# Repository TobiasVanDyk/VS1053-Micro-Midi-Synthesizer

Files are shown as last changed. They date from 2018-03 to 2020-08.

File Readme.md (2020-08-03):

# VS1053 Micro Midi Synthesizer

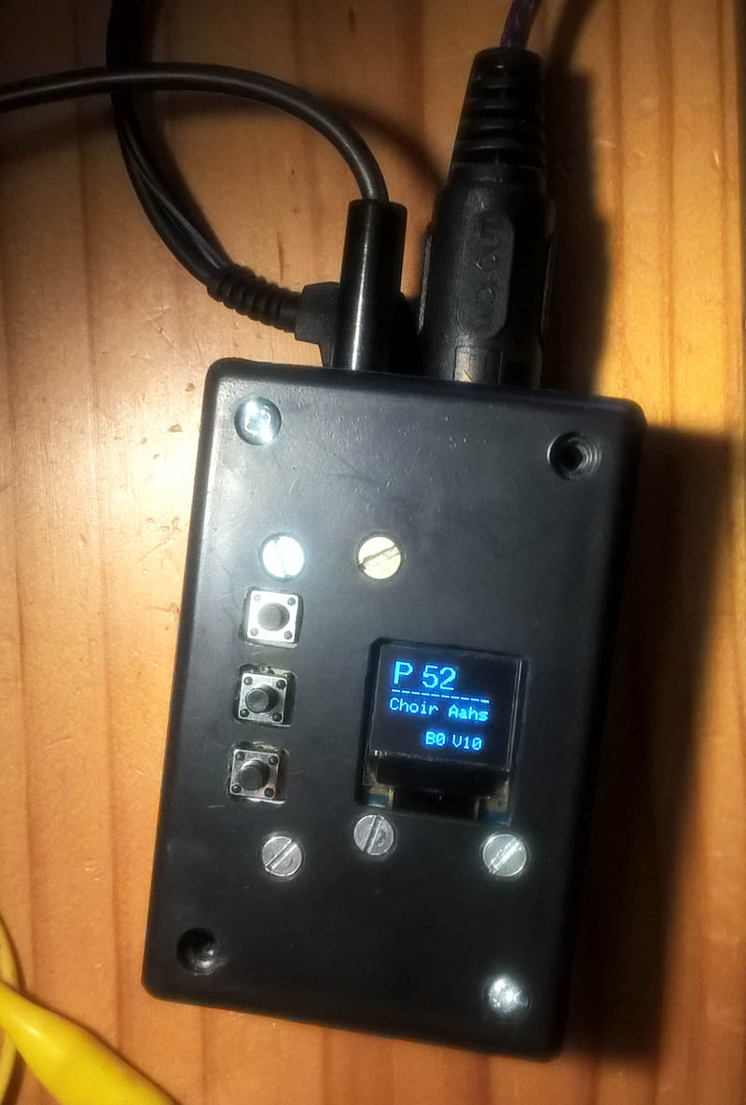
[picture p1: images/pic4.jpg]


### Introduction: 

This is also available as an [**instructable**](https://www.instructables.com/id/Micro-Midi-Synthesizer/), and demonstrates the use of the VLSI VS1053b Audio and Midi DSP chip in its real-time Midi mode. In this mode it acts as a 64 voice polyphonic GM (General Midi) Midi synthesizer. 

An ATMega328 MCU controls an OLED display, three buttons (Function Select and Up or Down, and passes the Midi data stream through to the audio DSP. The music board chosen was the Adafruit VS1053 codec breakout board, but a Sparkfun music breakout board was also successfully tested. The Adafruit VS1053b libraries were used instead of the much larger SFEMP3 Library (recommended by Sparkfun even though they also have their own set of libraries), because I found the Adafruit code easier to understand.

Most of the code used to control the audio/midi DSP was developed using an Arduino Uno connected to the audio/midi breakout board through a breadboard. After the functions were found to work satisfactory the Uno was used as a programmer for a standalone ATmega 328 which was then put on a small 30x20 size Veroboard together with the 6N139 opto-isolator IC required on the Midi input socket (a 5 pin DIN). Also connected was a small (64x48) OLED shield, three buttons, a Midi activity LED, and a +5 volt barrel connector for power and the audio stereo output connector added. The power requirements are very modest - about 20 mA at 5 volt.

### Parts List

* ATmega328 Micro 28 pin DIP + 28 pin DIP socket 
* 6N138 or 6N139 optoisolator + 4 pin DIP socket 
* Wemos 64x48 I2C OLED Display or similar 
* Adafruit VS1053b Codec breakout board 
* 3 miniature pushbuttons 
* 5 pin DIN Midi socket PCB mount preferred 
* Small LED any colour
* Barrel type power socket for the 5v supply 
* Stereo audio socket to connect to an amplifier or headphones 
* Resistors: 7 x 10k, 2 x 470 ohm, 2 x 220 ohm 
* Capacitors: 0.1uF 50v plastic, 10uf 25v electrolytic, 2 x 27 pF ceramic 
* Small pieces of Veroboard (30 strips by 20 columns, and 4 strips by 16 columns), ABS plastic enclosure about 85x55x25mm, wiring and a few screws nuts and washers.

### Construction

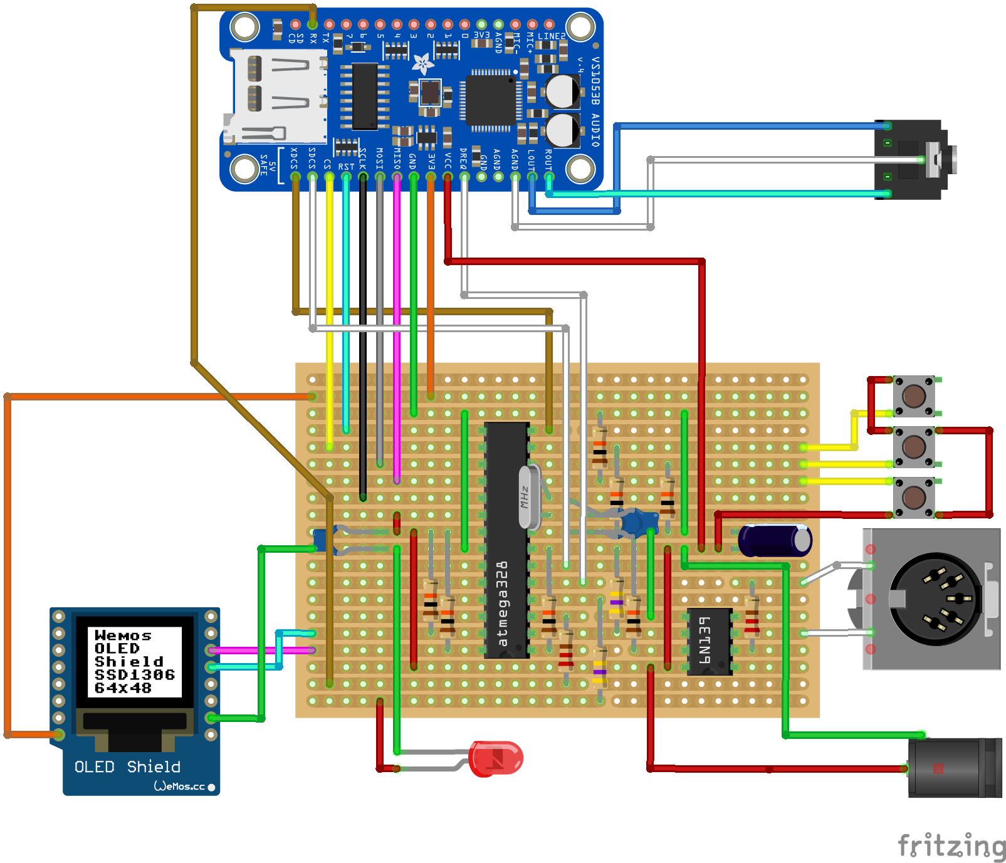
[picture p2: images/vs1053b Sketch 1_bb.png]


The lid of the enclosure houses the OLED Display, the three buttons that are mounted on another small piece of Veroboard, and the barrel power connector. The main Vero circuit board has two holes to fix the Music breakout board above the ATmega328. For connection details please refer to the Fritzing strip board diagram.
The programmed ATmega328 (please refer to the next section for the code) is then inserted into its socket followed by the 6N139 and everything is connected up.
The LED is used as a Midi activity indicator and was mounted on the front side of the enclosure. It is connected to the D2 output of the ATmega328 via a 470 ohm resistor.
The OLED Display use the 3.3 volt output from the Adafruit board for power - it requires less than 20 mA.
Try swapping the two Midi Din connections if you do not hear any audio when you first use the synth.

<p align="center">
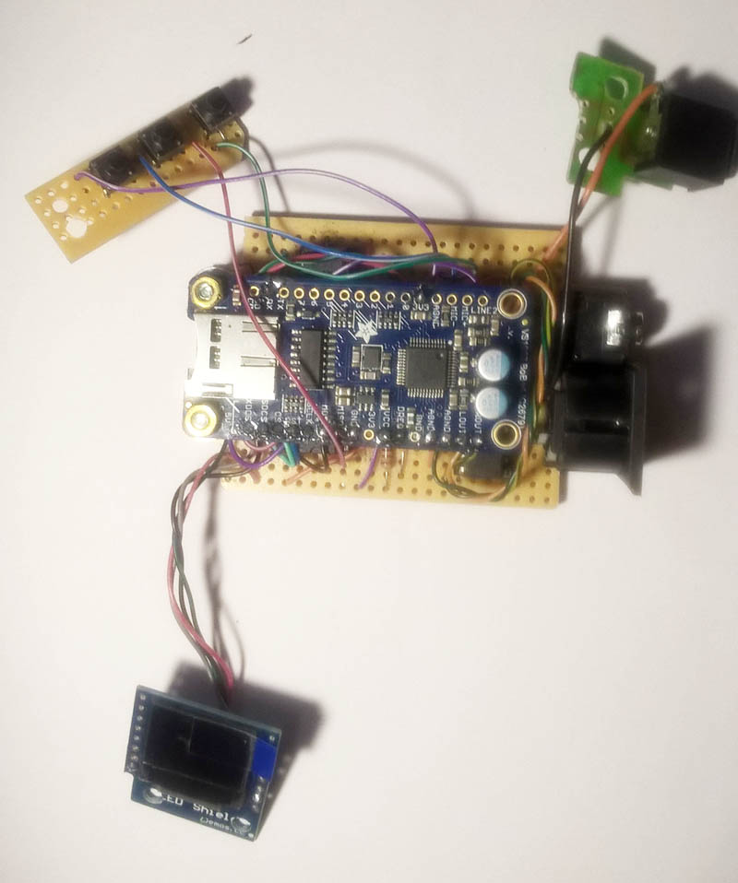
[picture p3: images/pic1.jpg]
  
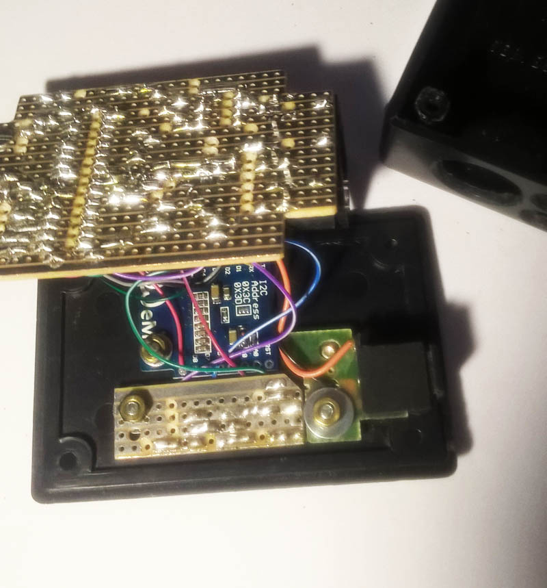
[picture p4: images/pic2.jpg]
  
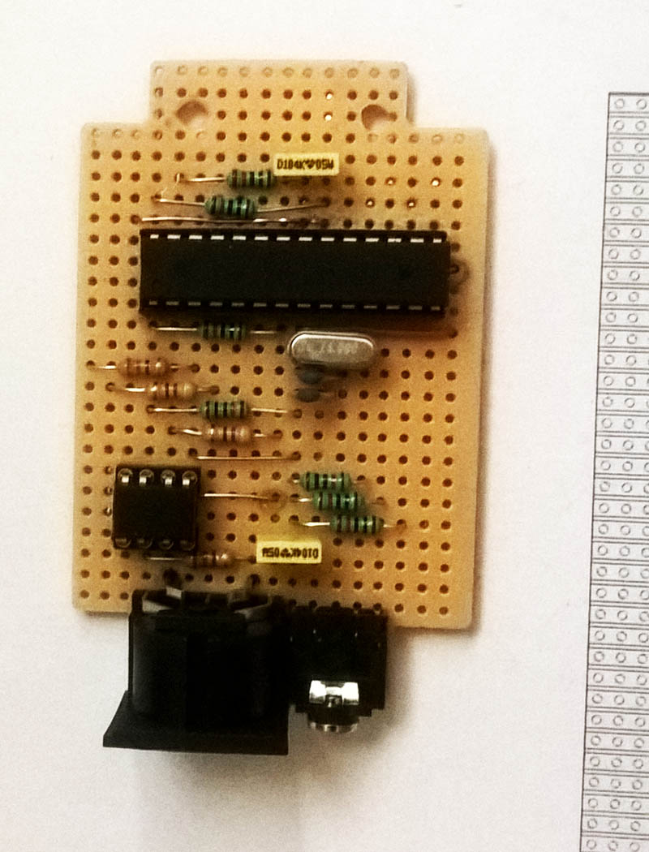
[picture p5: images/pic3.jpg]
  
</p>

### Software

Details of the sketch that should be uploaded to the ATmega328 is given in MidA.ino. There are seven functions available:
Option P: Change Program - change the GM Midi Instrument from 1 to 128 (I used 0 to 127) such as a Piano or Synth sound. Option B: Change the Instrument bank between Melodic (Bank 0) and Percussion (Bank 1). Option V: Adjust the volume from 1 to 10. Option C: Change the Midi channel that the Synth will respond to. The choices are Channel 0, channel 1, channel 9 (percussion), channel 0 and 9, and channel 1 and 9. Option R: Switch the Reverb effect on or off. Option S: Save the current parameters to Eeprom memory (Up) or Read (Down) it back from the Eeprom memory. This is because settings are otherwise not saved when powering down. Option X: Send an all notes off message (Midi Reset).

An eighth option is not yet implemented - this will bypass the ATmega as a Midi filter and connect the output of the optoisolator directly to the Rx pin of the DSP board.

Note that the VS1053b boots in a real-time Midi mode by loading a 1039 byte compressed patch during booting - this also increases the size of the Midi buffer and filters system exclusive Midi data bytes. Details of this patch can be found on the VLSI website.

A slightly modified version of the Adafruit Graphics library had been used to cater for the 64x48 pixel resolution of the OLED Display - please refer to the links given at the end for Mr Mcauser. A list of the required libraries is given in the sketch code.

Importantly when the sketch is executed for the first time on the ATmega328 whether it is on an Uno or standalone, the code will load parameter presets from the ATmega328 Eeprom that may not be valid. In that case you can either write all zeroes to the Eeprom using the X option with the down button, or comment out the line in the void setup function that loads values from the Eeprom when it is first started, adjust your instruments etc. to your liking, and then save your presets with the S option Up button.

Credit is given to all the persons and entities mentioned for their code and libraries..

### Links

* VLSI: http://www.vlsi.fi/en/home.html
* Adafruit: https://www.adafruit.com/product/1381
* Github VS1053b: https://github.com/adafruit/Adafruit_VS1053_Library
* Github Graphics: https://github.com/mcauser/Adafruit_SSD1306/tree/esp8266-64x48
* Oled: https://wiki.wemos.cc/products:d1_mini_shields:oled_shield
* Sparkfun: https://www.sparkfun.com/products/12660

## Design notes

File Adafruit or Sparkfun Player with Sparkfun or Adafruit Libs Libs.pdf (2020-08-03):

Use Adafruit Player with Sparkfun SFEMP Libraries:

Connect Adafruit Player to Arduino Uno pins using the Sparkfun layout (green = same connection):

Connect Sparkfun Player to Arduino Uno pins using the Adafruit layout (green = same connection):

Adafruit → | Uno – SparkfunLibs | Uno – Afafruit Libs | Sparkfun
Shield | | | Shield
VCC | 5v | 5v | 5v
GND | GND | GND | GND
SCLK | Arduino #13 | Arduino #13 | 13
MISO | Arduino #12 | Arduino #12 | 12
MOSI | Arduino #11 | Arduino #11 | 10
CS | Arduino #6 | Arduino #10 | 6 MP3-CS
RST | Arduino #8 | Arduino #9 | 8 MP3-RST
XDCS | Arduino #7 | Arduino #8 | 7 MP3-DCS
SDCS | Arduino #9 | Arduino #4 | 9 SC-CS
DREQ | Arduino #2 | Arduino #3 | 2 MP3-DREQ
RX-Midi | Arduino #3
| Arduino Tx #1 | | 3 MIDI-IN RX

Adafruit Shield with SFEMP3 Libs: GPIO1 and GPIO0 can be left unconnected or connected to GND.
Can now use the SFEMP3Shield libraries on the Adafruit.
To play Flac must put patchesf.053 in root of SD Card and change patches.053 to patchesf.053 in SFEMP3Shield.cpp. Then use FilePlayer.ino with indexes ie.e 0005 etc to select the .fla file (not .flac).
MP3Shield_Library_Demo.ino only able to play .mp3 files else must change the code.

Sparkfun Shield with SFEMP3 Libs: Pins 5 and 4 leave unconnected

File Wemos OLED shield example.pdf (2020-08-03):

Wemos OLED shield example

In this example we look at another terrific little low cost shield for the Wemos mini, this time its the OLED shield. Lets look at the shield and some specs

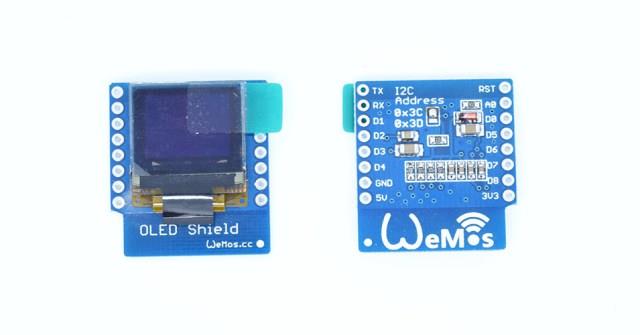
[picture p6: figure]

- Screen Size: 64×48 pixels (0.66” Across)
- Operating Voltage: 3.3V
- Driver IC: SSD1306
- Interface: IIC(I2C)
- IIC Address: 0x3C or 0x3D

The shield uses the I2C pins, so you can still connect another I2C device (if it uses a different address) and the other pins are available

D1 mini | Shield
D1 | SCL
D2 | SDA

Code

You will need to add the https://github.com/mcauser/Adafruit_SSD1306 library

The following code example is a simple hello world type example

Source code (http://www.esp8266learning.com/wemos-oled-shield-example.php#codesyntax_3)

#include <SPI.h>

#include <Wire.h>

#include <Adafruit_GFX.h>

#include <Adafruit_SSD1306.h>

// SCL GPIO5
// SDA GPIO4
#define OLED_RESET 0 // GPIO0 Adafruit_SSD1306 display(OLED_RESET);

#define NUMFLAKES 10

#define XPOS 0

#define YPOS 1

#define DELTAY 2

#define LOGO16_GLCD_HEIGHT 16

#define LOGO16_GLCD_WIDTH | 16

void setup() | {
Serial.begin(9600);

// by default, we'll generate the high voltage from the 3.3v line internally! (neat!) display.begin(SSD1306_SWITCHCAPVCC, 0x3C); // initialize with the I2C addr 0x3C (for the 64x48)
// init done

display.display();
delay(2000);

// Clear the buffer.
display.clearDisplay();

// text display tests
display.setTextSize(1);
display.setTextColor(WHITE); display.setCursor(0,0);
display.println("Hello, world!"); display.display();
delay(2000);
display.clearDisplay();

}

void loop() {

}

Links
OLED Shield for WeMos D1 mini 0.66″ inch 64X48 IIC I2C Compatible (http://s.click.aliexpress.com/e/3RFYr7YRV)
4 comments to Wemos OLED shield example

Mike Morrow
28th August 2017 at 7:46 am · Reply

Here’s what I had to do to see anything on the screen. (0,0) is too high and too far left

// text display tests
display.setTextSize(1);
display.setTextColor(WHITE);
display.setCursor(32,20);
display.println(“Hello, world!”); display.display();

HYKGOML
1st October 2017 at 2:32 am · Reply

// text display tests
display.setTextSize(1);
display.setTextColor(WHITE); display.setCursor(31,8);
display.println(“123456789AB”); display.setCursor(31,16);
display.println(“123456789AB”); display.setCursor(31,24);
display.println(“123456789AB”); display.display();
delay(2000);

display.clearDisplay();

Miguel Angel Casanova
7th October 2017 at 9:09 pm · Reply

Thanks Mike Morrow, you are right! ..

Greg Woods
12th October 2017 at 12:49 am · Reply

@Mike Morrow. It’s because the Adafruit library isn’t designed for 64*48 displays. A forked version will likely work. It’s just finding one that is the problem. There are 326 forks… of varying quality!

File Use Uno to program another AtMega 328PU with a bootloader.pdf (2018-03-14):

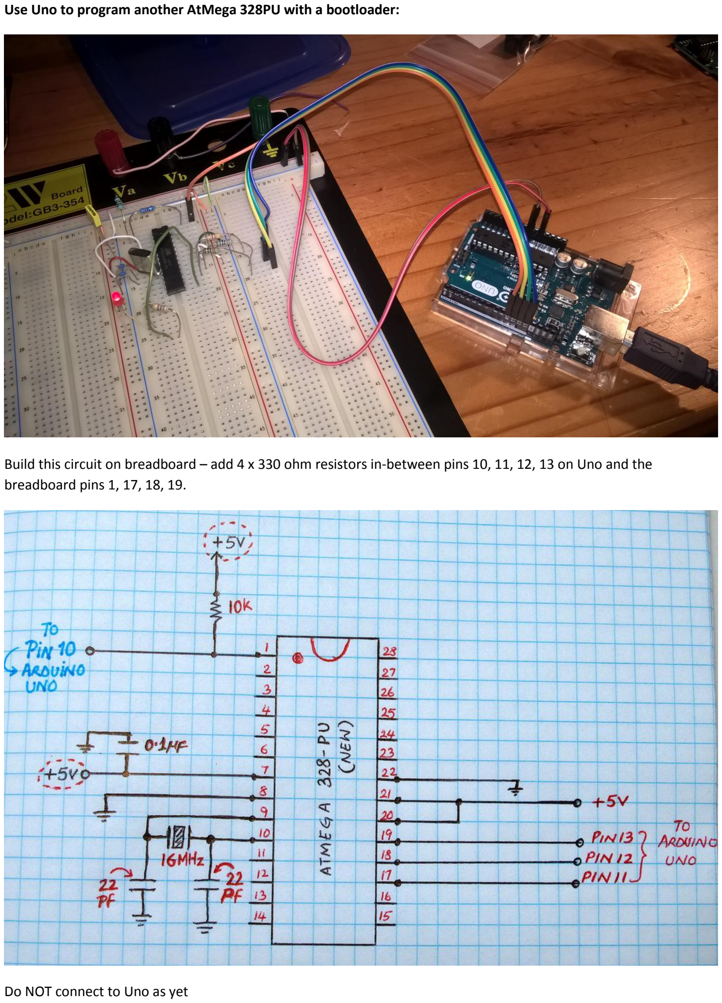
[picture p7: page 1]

Use Uno to program another AtMega 328PU with a bootloader:

Build this circuit on breadboard – add 4 x 330 ohm resistors in-between pins 10, 11, 12, 13 on Uno and the breadboard pins 1, 17, 18, 19.

Do NOT connect to Uno as yet

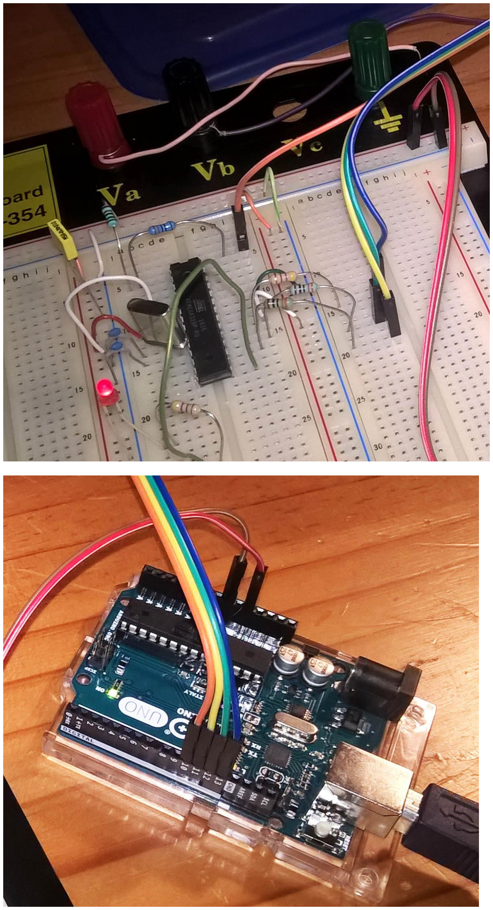
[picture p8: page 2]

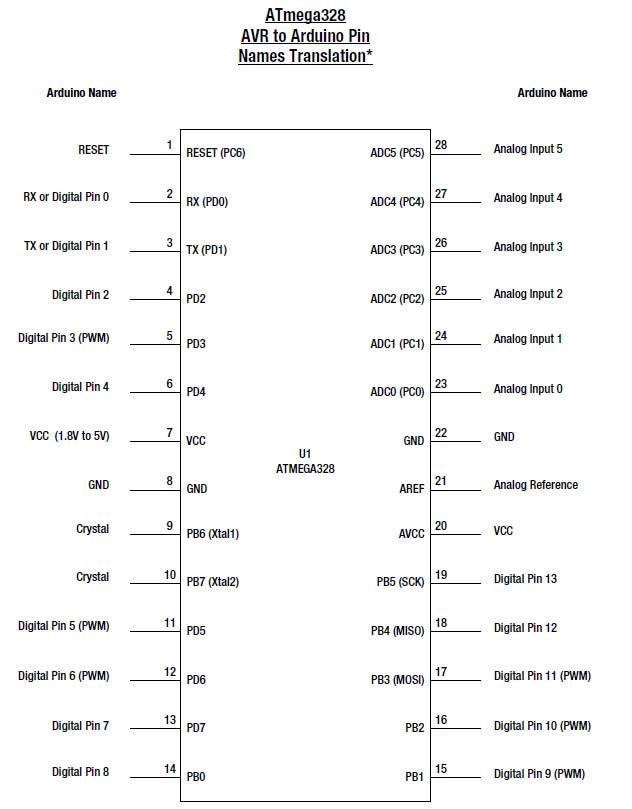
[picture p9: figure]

Connect Uno with an usb cable and start Arduino ide

Check that correct com port is chosen (if another Uno is plugged in it will have a different com number)

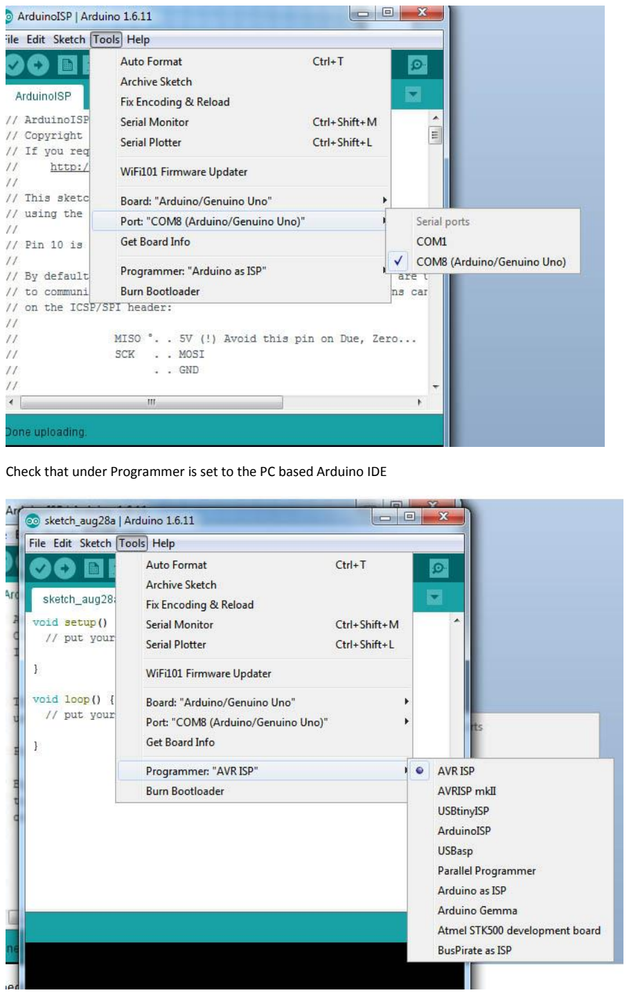
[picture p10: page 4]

Check that under Programmer is set to the PC based Arduino IDE

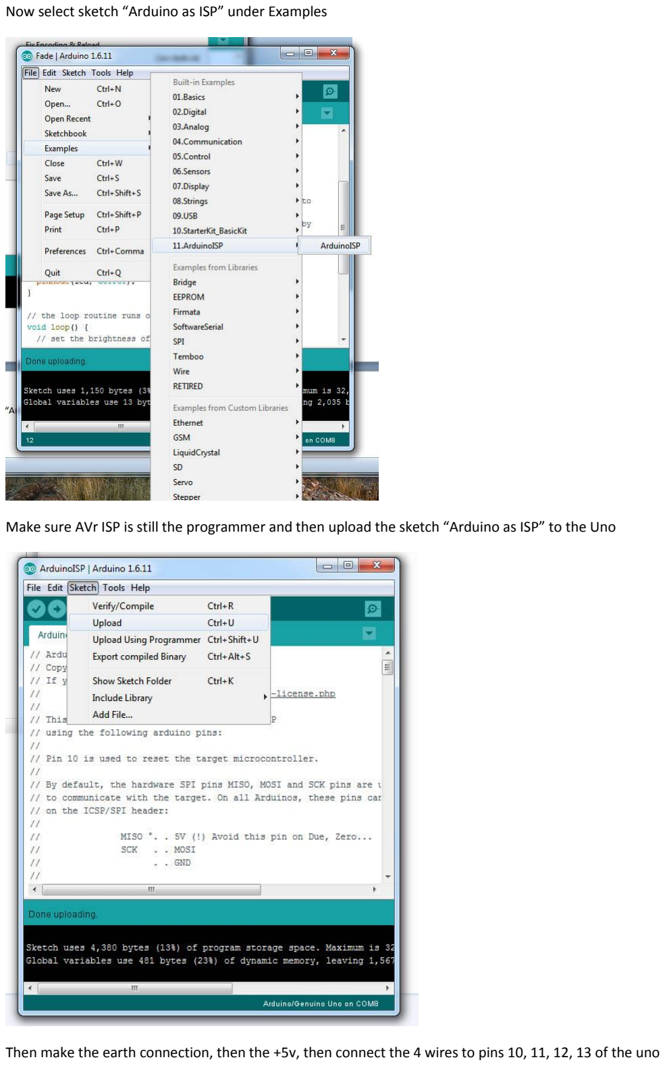
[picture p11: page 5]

Now select sketch “Arduino as ISP” under Examples

Make sure AVr ISP is still the programmer and then upload the sketch “Arduino as ISP” to the Uno

Then make the earth connection, then the +5v, then connect the 4 wires to pins 10, 11, 12, 13 of the uno

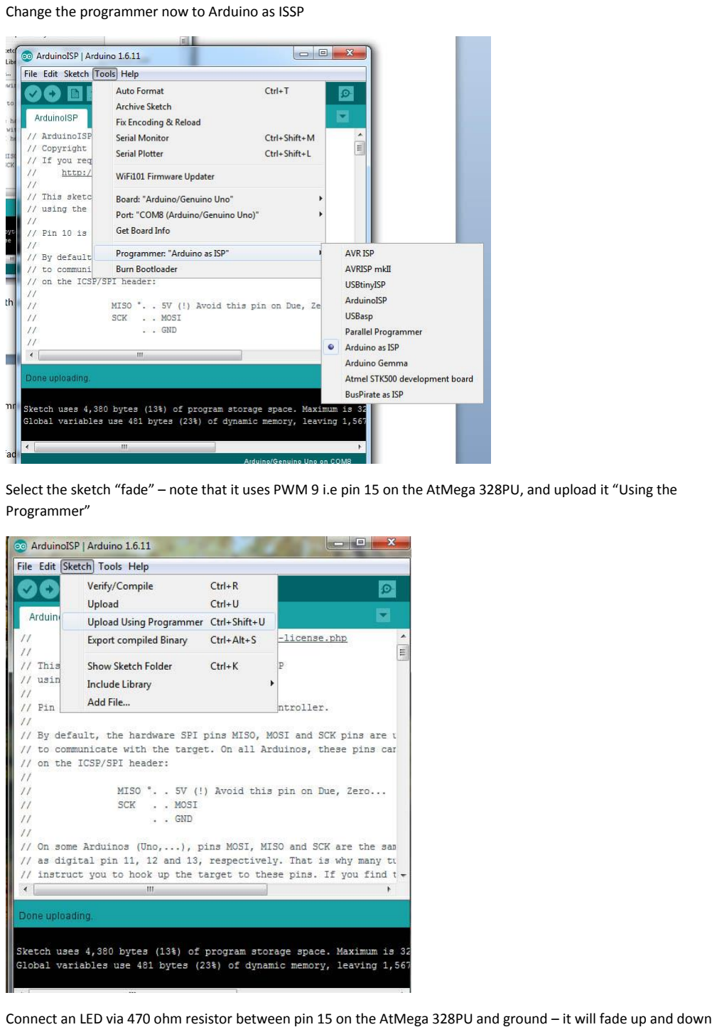
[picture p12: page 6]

Change the programmer now to Arduino as ISSP

Select the sketch “fade” – note that it uses PWM 9 i.e pin 15 on the AtMega 328PU, and upload it “Using the Programmer”

Connect an LED via 470 ohm resistor between pin 15 on the AtMega 328PU and ground – it will fade up and down

Note that if the blink sketch is uploaded it uses pin P13 which is connected to the Uno pin 13 which can cause a conflict

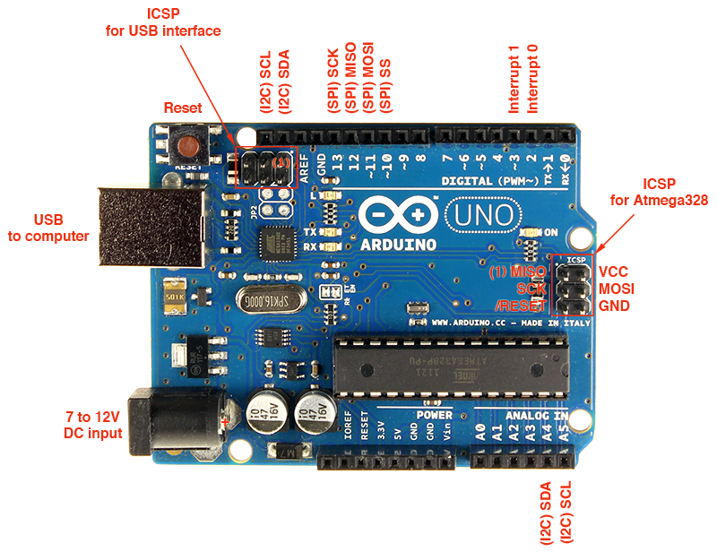
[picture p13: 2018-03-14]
images/ArduinoUno_R3_Pinouts.png

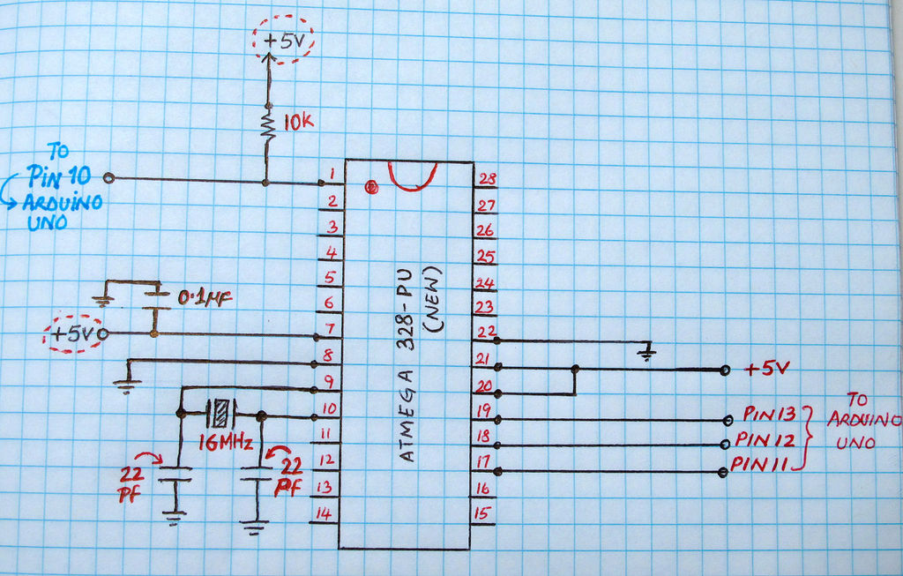
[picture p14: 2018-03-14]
images/FL5F0G7HSE9270L_LARGE.jpg

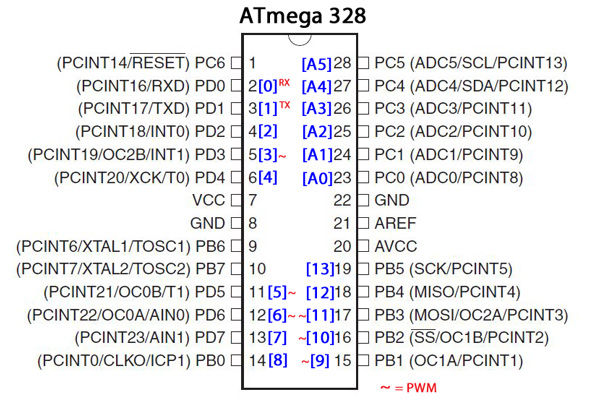
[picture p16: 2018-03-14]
images/Uno.jpg

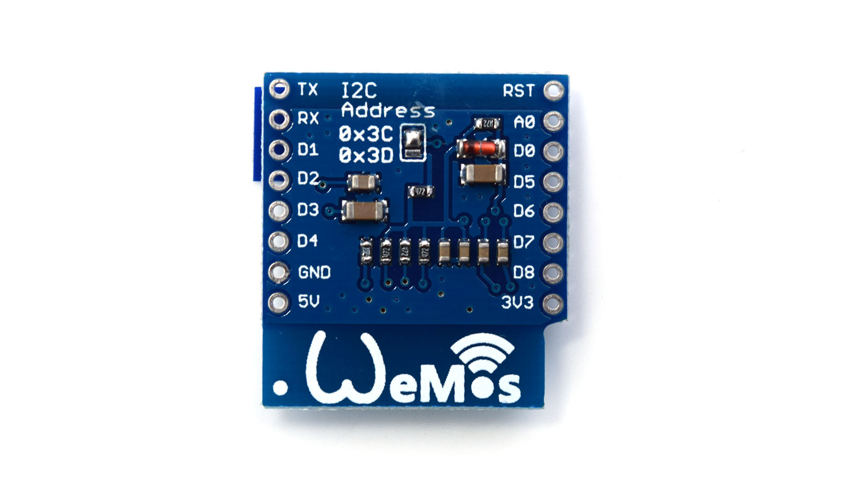
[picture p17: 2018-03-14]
images/oled2.png

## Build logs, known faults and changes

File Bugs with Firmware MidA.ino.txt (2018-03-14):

(1) When state is saved in flash memory channel 0 params are save but channel 1 instrument is not read correctly after rebooting
(2) Actually need more than just 3 midi channels active for example when playing amidi file many instruments could be spread across many midi channels. Threfore need a sixth option "All cahnnel" in the Midi channels function

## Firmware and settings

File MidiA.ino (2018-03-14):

/****************************************************************************************** 
 * This is an example for the Adafruit VS1053 Codec Breakout
 * 
 * Designed specifically to work with the Adafruit VS1053 Codec Breakout 
 * ----> https://www.adafruit.com/products/1381
 * 
 * Adafruit invests time and resources providing this open source code, 
 * please support Adafruit and open-source hardware by purchasing 
 * products from Adafruit!
 * 
 * Written by Limor Fried/Ladyada for Adafruit Industries.  
 * BSD license, all text above must be included in any redistribution
 * Code adapted By Tobias van Dyk for use with an Adafruit VS1053 module and an Arduino Uno
 ********************************************************************************************/
 // VS1103b MIDI Controls
 // The implemented midi messages here. Some like tempo are used in file mode only. 
 // meta: 0x51 : set tempo
 // other meta: MidiMeta() called (user code can send out lyrics and other meta information)
 // SysEx device control: 0x01 : master volume (only in file mode!)
 // channel message: 0x80 note off, 0x90 note on, 0xc0 program, 0xe0 pitch wheel
 // channel message 0xb0: parameter ? 0x00: bank select (0 is default, 0x78 and 0x7f is drums, 0x79 melodic)
 //         0x06: RPN MSB: 0 = bend range, 2 = coarse tune
 //         0x07: channel volume
 //         0x0a: pan control
 //         0x0b: expression (changes volume)
 //         0x0c: effect control 1 (sets global reverb decay)
 //         0x26: RPN LSB: 0 = bend range
 //         0x40: hold1
 //         0x42: sustenuto
 //         0x5b effects level (channel reverb level)
 //         0x62,0x63,0x64,0x65: NRPN and RPN selects
 //         0x78: all sound off
 //         0x79: reset all controllers
 //         0x7b, 0x7c, 0x7d: all notes off
 // 
 // The channel-specific level and overall 'duration' of reverb can be adjusted, "expression" adjusts the volume of audible notes on that 
 // channel, and pitch-wheel adjusts the note frequencies.
 //
 // All 16 channels and multiple notes per channel are available. The total simultaneous audible notes depends on the clock frequency and 
 // what instruments are used (different instruments take varying amounts of processing power).
 //
 // Reverb: There are 15 different default Reverb settings in the low 4 bits of the parametric_x.config1 register (X:0x1e03). Values 2 to 15
 // select a default room size (internal 350 to 4900). 0 will enable the reverb depending on the value of CLOCKF (3.0x or higher clock enables
 // reverb). 1 means reverb is disabled. When you control Reverb through MIDI controls (Parameter / effect control 1), all control values from
 // 0 to 127 are valid (internal 0..4064). In vs1103b Reverb is mutually exclusive with EarSpeaker.
 //

byte Instrument = 0x00;
byte SavedInstrument = 0x00;
byte Instrument0 = 0x00;        // Channel 0
byte SavedInstrument0 = 0x00;
byte Instrument1 = 0x00;        // Channel 1 Channel 10 is percussion
byte SavedInstrument1 = 0x00;
byte Bank = 0x00; // Valid Banks for VS1053 0x00 0x78 0x79
byte Reverb = 0; // off
byte EPrm = 0;   // Eeprom saved

int FunctionNum = 1;                                // 1 is Change Instrument Program P  Can take value 1 to 8
const char* const Function PROGMEM = " PBVCRSXbt "; // Function Indicator P = Change Intrumnet (Midi Program Change) 
//booleans to activate when btnpressed
boolean AnyBtnPress = false;
byte Volume = 1;
byte Channel = 0; // VS1053 receives on all Midi Channels 1 to 16

// include SPI, SD, Wire Adafruit_VS1053, GFX and SSD libraries
#include <SPI.h>
#include <Adafruit_VS1053.h>
#include <SD.h>
#include <avr/pgmspace.h>
#include <Wire.h>
#include <EEPROM.h>
#include <Adafruit_GFX.h>
#include <Adafruit_SSD1306.h>
#include <Fonts/FreeSans9pt7b.h>

// Pin Numbers
#define btnPrev 5  // D5 Down Button
#define btnNext 6  // D6 Up Button
#define btnFunc 7  // D7 Select Function
#define MidiLED 2  // D2 Show Midi Activity
// define the other pins used
#define VS1053_RESET 9         // This is the pin that connects to the RESET pin on VS1053
//#define CLK 13               // SPI Clock, shared with SD card
//#define MISO 12              // Input data, from VS1053/SD card
//#define MOSI 11              // Output data, to VS1053/SD card
// Connect CLK, MISO and MOSI to hardware SPI pins. 
// These are the pins used for the breakout example
#define BREAKOUT_RESET  9      // VS1053 reset pin (output) rst 
#define BREAKOUT_CS     10     // VS1053 chip select pin (output) cs 
#define BREAKOUT_DCS    8      // VS1053 Data/command select pin (output) xdcs 
// These are the pins used for the music maker shield
#define SHIELD_CS     7        // VS1053 chip select pin (output)
#define SHIELD_DCS    6        // VS1053 Data/command select pin (output)
// These are common pins between breakout and shield
#define CARDCS 4               // Card chip select pin sdcs 
// DREQ should be an Int pin i.e. Arduino Uno Pin 2 or 3
#define DREQ 3                 // VS1053 Data request, ideally an Interrupt pin 
#define RESET 9                // VS1053 reset pin (RST) (output)
#define CS 10                  // VS1053 chip select pin (CS) (output)
#define DCS 8                  // VS1053 Data/command select pin (XDCS) (output)

#define OLED_RESET 0     // GPIO0
Adafruit_SSD1306 display(OLED_RESET);
#if (SSD1306_LCDHEIGHT != 48)
#error("Height incorrect, please fix Adafruit_SSD1306.h!");
#endif

// General Midi Instruments
#define InstrNumber 128
// Piano Family:
const char Instr000[] PROGMEM = "Acoustic Grand Piano";
const char Instr001[] PROGMEM = "Bright Acoustic Piano";
const char Instr002[] PROGMEM = "Electric Grand Piano";
const char Instr003[] PROGMEM = "Honky-tonk Piano";
const char Instr004[] PROGMEM = "Electric Piano 1";
const char Instr005[] PROGMEM = "Electric Piano 2";
const char Instr006[] PROGMEM = "Harpsichord";
const char Instr007[] PROGMEM = "Clavinet";
// Chromatic Percussion Family:
const char Instr008[] PROGMEM = "Celesta";
const char Instr009[] PROGMEM = "Glockenspiel";
const char Instr010[] PROGMEM = "Music Box";
const char Instr011[] PROGMEM = "Vibraphone";
const char Instr012[] PROGMEM = "Marimba";
const char Instr013[] PROGMEM = "Xylophone";
const char Instr014[] PROGMEM = "Tubular Bells";
const char Instr015[] PROGMEM = "Dulcimer";
// Organ Family:
const char Instr016[] PROGMEM = "Drawbar Organ";
const char Instr017[] PROGMEM = "Percussive Organ";
const char Instr018[] PROGMEM = "Rock Organ";
const char Instr019[] PROGMEM = "Church Organ";
const char Instr020[] PROGMEM = "Reed Organ";
const char Instr021[] PROGMEM = "Accordion";
const char Instr022[] PROGMEM = "Harmonica";
const char Instr023[] PROGMEM = "Tango Accordion";
// Guitar Family:
const char Instr024[] PROGMEM = "Acoustic Guitar (nylon)";
const char Instr025[] PROGMEM = "Acoustic Guitar (steel)";
const char Instr026[] PROGMEM = "Electric Guitar (jazz)";
const char Instr027[] PROGMEM = "Electric Guitar (clean)";
const char Instr028[] PROGMEM = "Electric Guitar (muted)";
const char Instr029[] PROGMEM = "Overdriven Guitar";
const char Instr030[] PROGMEM = "Distortion Guitar";
const char Instr031[] PROGMEM = "Guitar harmonics";
// Bass Family:
const char Instr032[] PROGMEM = "Acoustic Bass";
const char Instr033[] PROGMEM = "Electric Bass (finger)";
const char Instr034[] PROGMEM = "Electric Bass (pick)";
const char Instr035[] PROGMEM = "Fretless Bass";
const char Instr036[] PROGMEM = "Slap Bass 1";
const char Instr037[] PROGMEM = "Slap Bass 2";
const char Instr038[] PROGMEM = "Synth Bass 1";
const char Instr039[] PROGMEM = "Synth Bass 2";
// Strings Family:
const char Instr040[] PROGMEM = "Violin";
const char Instr041[] PROGMEM = "Viola";
const char Instr042[] PROGMEM = "Cello";
const char Instr043[] PROGMEM = "Contrabass";
const char Instr044[] PROGMEM = "Tremolo Strings";
const char Instr045[] PROGMEM = "Pizzicato Strings";
const char Instr046[] PROGMEM = "Orchestral Harp";
const char Instr047[] PROGMEM = "Timpani";
// Ensemble Family:
const char Instr048[] PROGMEM = "String Ensemble 1";
const char Instr049[] PROGMEM = "String Ensemble 2";
const char Instr050[] PROGMEM = "Synth Strings 1";
const char Instr051[] PROGMEM = "Synth Strings 2";
const char Instr052[] PROGMEM = "Choir Aahs";
const char Instr053[] PROGMEM = "Voice Oohs";
const char Instr054[] PROGMEM = "Synth Voice";
const char Instr055[] PROGMEM = "Orchestra Hit";
// Brass Family:
const char Instr056[] PROGMEM = "Trumpet";
const char Instr057[] PROGMEM = "Trombone";
const char Instr058[] PROGMEM = "Tuba";
const char Instr059[] PROGMEM = "Muted Trumpet";
const char Instr060[] PROGMEM = "French Horn";
const char Instr061[] PROGMEM = "Brass Section";
const char Instr062[] PROGMEM = "Synth Brass 1";
const char Instr063[] PROGMEM = "Synth Brass 2";
// Reed Family:
const char Instr064[] PROGMEM = "Soprano Sax";
const char Instr065[] PROGMEM = "Alto Sax";
const char Instr066[] PROGMEM = "Tenor Sax";
const char Instr067[] PROGMEM = "Baritone Sax";
const char Instr068[] PROGMEM = "Oboe";
const char Instr069[] PROGMEM = "English Horn";
const char Instr070[] PROGMEM = "Bassoon";
const char Instr071[] PROGMEM = "Clarinet";
// Pipe Family:
const char Instr072[] PROGMEM = "Piccolo";
const char Instr073[] PROGMEM = "Flute";
const char Instr074[] PROGMEM = "Recorder";
const char Instr075[] PROGMEM = "Pan Flute";
const char Instr076[] PROGMEM = "Blown Bottle";
const char Instr077[] PROGMEM = "Shakuhachi";
const char Instr078[] PROGMEM = "Whistle";
const char Instr079[] PROGMEM = "Ocarina";
// Synth Lead Family:
const char Instr080[] PROGMEM = "Lead 1 (square)";
const char Instr081[] PROGMEM = "Lead 2 (sawtooth)";
const char Instr082[] PROGMEM = "Lead 3 (calliope)";
const char Instr083[] PROGMEM = "Lead 4 (chiff)";
const char Instr084[] PROGMEM = "Lead 5 (charang)";
const char Instr085[] PROGMEM = "Lead 6 (voice)";
const char Instr086[] PROGMEM = "Lead 7 (fifths)";
const char Instr087[] PROGMEM = "Lead 8 (bass)";
// Synth Pad Family:
const char Instr088[] PROGMEM = "Pad 1 (new age)";
const char Instr089[] PROGMEM = "Pad 2 (warm)";
const char Instr090[] PROGMEM = "Pad 3 (polysynth)";
const char Instr091[] PROGMEM = "Pad 4 (choir)";
const char Instr092[] PROGMEM = "Pad 5 (bowed)";
const char Instr093[] PROGMEM = "Pad 6 (metallic)";
const char Instr094[] PROGMEM = "Pad 7 (halo)";
const char Instr095[] PROGMEM = "Pad 8 (sweep)";
// Synth Effects Family:
const char Instr096[] PROGMEM = "FX 1 (rain)";
const char Instr097[] PROGMEM = "FX 2 (soundtrack)";
const char Instr098[] PROGMEM = "FX 3 (crystal)";
const char Instr099[] PROGMEM = "FX 4 (atmosphere)";
const char Instr100[] PROGMEM = "FX 5 (brightness)";
const char Instr101[] PROGMEM = "FX 6 (goblins)";
const char Instr102[] PROGMEM = "FX 7 (echoes)";
const char Instr103[] PROGMEM = "FX 8 (scifi)";
// Ethnic Family:
const char Instr104[] PROGMEM = "Sitar";
const char Instr105[] PROGMEM = "Banjo";
const char Instr106[] PROGMEM = "Shamisen";
const char Instr107[] PROGMEM = "Koto";
const char Instr108[] PROGMEM = "Kalimba";
const char Instr109[] PROGMEM = "Bag pipe";
const char Instr110[] PROGMEM = "Fiddle";
const char Instr111[] PROGMEM = "Shanai";
// Percussive Family:
const char Instr112[] PROGMEM = "Tinkle Bell";
const char Instr113[] PROGMEM = "Agogo";
const char Instr114[] PROGMEM = "Steel Drums";
const char Instr115[] PROGMEM = "Woodblock";
const char Instr116[] PROGMEM = "Taiko Drum";
const char Instr117[] PROGMEM = "Melodic Tom";
const char Instr118[] PROGMEM = "Synth Drum";
const char Instr119[] PROGMEM = "Reverse Cymbal";
// Sound Effects Family:
const char Instr120[] PROGMEM = "Guitar Fret Noise";
const char Instr121[] PROGMEM = "Breath Noise";
const char Instr122[] PROGMEM = "Seashore";
const char Instr123[] PROGMEM = "Bird Tweet";
const char Instr124[] PROGMEM = "Telephone Ring";
const char Instr125[] PROGMEM = "Helicopter";
const char Instr126[] PROGMEM = "Applause";
const char Instr127[] PROGMEM = "Gunshot";

const char Instr128[] PROGMEM = "PercussionInstrument";

const char* const InstrBank1[] PROGMEM = 
{ Instr000, Instr001, Instr002, Instr003, Instr004, Instr005, Instr006, Instr007, Instr008, Instr009, Instr010, Instr011, Instr012, Instr013, Instr014, Instr015, 
  Instr016, Instr017, Instr018, Instr019, Instr020, Instr021, Instr022, Instr023, Instr024, Instr025, Instr026, Instr027, Instr028, Instr029, Instr030, Instr031, 
  Instr032, Instr033, Instr034, Instr035, Instr036, Instr037, Instr038, Instr039, Instr040, Instr041, Instr042, Instr043, Instr044, Instr045, Instr046, Instr047, 
  Instr048, Instr049, Instr050, Instr051, Instr052, Instr053, Instr054, Instr055, Instr056, Instr057, Instr058, Instr059, Instr060, Instr061, Instr062, Instr063, 
  Instr064, Instr065, Instr066, Instr067, Instr068, Instr069, Instr070, Instr071, Instr072, Instr073, Instr074, Instr075, Instr076, Instr077, Instr078, Instr079, 
  Instr080, Instr081, Instr082, Instr083, Instr084, Instr085, Instr086, Instr087, Instr088, Instr089, Instr090, Instr091, Instr092, Instr093, Instr094, Instr095, 
  Instr096, Instr097, Instr098, Instr099, Instr100, Instr101, Instr102, Instr103, Instr104, Instr105, Instr106, Instr107, Instr108, Instr109, Instr110, Instr111, 
  Instr112, Instr113, Instr114, Instr115, Instr116, Instr117, Instr118, Instr119, Instr120, Instr121, Instr122, Instr123, Instr124, Instr125, Instr126, Instr127, Instr128
};
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
void loop() {  
  //if ( onceonly == 0 ) 
  //{    
  //     onceonly ++;
  //}
  
  //check if the buttons are being pressed
  chkBtn();
  if (AnyBtnPress) readBtn();
  
  digitalWrite (MidiLED, LOW); // Midi activity indicator
  // Echo Midi from Arduino Rx to Tx
  // Arduino Rx to output op opto-isolator
  // Arduino Tx connected to VS1053 Rx via 220ohm resistor
  // Can then filter and manipulate Midi
  // NB: Must disconnect Arduino Rx temporarily whilest uploading sketch
  // Check if data has been sent from the computer using a three byte buffer 
  
     if (Serial.available()) 
     { // Read the most recent byte
       ReadByte = Serial.read();
       digitalWrite (MidiLED, HIGH);
       if (ReadByte==0xC0) DoInstr = 1; 
       // If it is NoteOn 0x90 or NoteOff 0x80 get Channel
       if ((ReadByte>0x7F)&&(ReadByte<0xA0)) ChannelTemp = ReadByte & 0x0F;
       // delay(1);
       // Echo the value that was read back to the serial port
       // Only resppond to selected Channel 0, 1 and/or 9 - Midispeak 1, 2, and/or 10 
       if (ChannelTemp==Channel) Serial.write(ReadByte);
       if ((ChannelSelect>2)&&(ChannelTemp==9)) Serial.write(ReadByte);
       if (DoInstr==1) { MidiByte[n] = ReadByte; n++; }
     }
       
     if (n==2) {   // Instrument Change MidLED will shine brightly here        
          DoInstr = 0; 
          n = 0;
          ChannelTemp = Channel; 
          Channel = MidiByte[0] & 0x0F;
          if (Channel==0) Instrument0 = MidiByte[1]; 
          if (Channel==1) Instrument1 = MidiByte[1];
          if (Channel<2) { ChangeInstr(2); DoDisplay2();} 
          Channel = ChannelTemp;
        }
                  
}


/*******************************************************************************************************************************/
// P Option 1: Change Program: Select Instrument from 0-127 with Up/Dwn Buttons. Can select different instruments for each 
//             channel 0 or 1 but channel 9 different keys are different percussion instruments
// B Option 2: Change Bank: Select from 0 or 1 i.e. Melodic or Percussion
// V Option 3: Volume up or down from 0 to 10
// C Option 4: Select channel 0, 1, 9, 0+9, 1+9 Will only receive noteon/off on these Midi channels 1, 2, 9 or 1 and 9 or 2 and 9
// R Option 5: Select Reverb on or off (0 or 1)
// S Option 6: Save or Read Saved Parameters Up is Write (Save) Parameters, Down is Read (Load) saved parameters back.
// X Option 7: Dwn is Reset, Up is All Notes of Midi 
// M Option 8: Select Midi Path - direct to VS1053 Rx, or via Arduino Rx echo to Arduino Tx and then to VS1053 Rx
//             Can do Midi filtering if not direct to VS1053 Rx
//             Also needs a physical two pole two way switch to reroute Midi signals to the two different Rx's
/********************************************************************************************************************************/

void DoDisplay2 ()
{
  char buffer1[24]; 
  
  //byte ChannelTwo = 0;
  //if (ChannelSelect>2) ChannelTwo = ChannelSelect - 3;
  
  byte RealVol = (0xFE - Volume)/5 - 40; // Max Volume is 0 now it is 10
  if (RealVol>100) RealVol = 0;
  
  if (FunctionNum<8)
    { display.setFont(&FreeSans9pt7b);
      display.setTextSize(1);
      display.setTextColor(WHITE);
      display.setCursor(0,12);
      display.clearDisplay();
      display.print(Function[FunctionNum]); 
      display.print(" ");
      
      if (FunctionNum==1) display.print(Instrument);
      if (FunctionNum==2) { if (Bank==0) display.print(Bank); else display.print("1"); }
      if (FunctionNum==3) display.print(RealVol);
      //if (FunctionNum==4) { display.print(Channel); display.print(" "); display.print(ChannelSelect);}
      if (FunctionNum==4) { display.print(Channel); if (ChannelSelect>2) display.print(" 9");}
      if (FunctionNum==5) display.print(Reverb);
      if (FunctionNum==6) { if (EPrm==1) display.print("r"); if (EPrm==2) display.print("w");}
      if (FunctionNum==7) display.print("r n");
      display.setFont();
      display.println();
      display.print("----------");
      if (Bank==0) {strcpy_P(buffer1, (char*)pgm_read_word(&(InstrBank1[Instrument]))); display.print(buffer1);}
      if (Bank!=0) {strcpy_P(buffer1, (char*)pgm_read_word(&(InstrBank1[128])));        display.print(buffer1);}
      
      // Always visble info at bottom
      display.setCursor(24,40);
      display.print("B");
      if (Bank==0) display.print(Bank); else display.print("1");
      display.setCursor(40,40);
      display.print("V");
      display.print(RealVol);
      
      display.display();
    } else delay(200);
}
/************************************/
// Bank 0: Instrument 0 to 127
// Bank 0x78: Instrument 0x1E
/************************************/
void ChangeInstr(byte UpDwn) // UpDwn 0 = Down Key 1 = Up Key 2 = Instrument Change via Midi Control
  {  if (Bank == 0) // Melodic Instrument
        { if (Channel==0) Instrument = Instrument0; else Instrument = Instrument1;
    
          if (UpDwn==1) {if (Instrument==127) Instrument = 0; else Instrument = Instrument + 1;}
          if (UpDwn==0) {if (Instrument==0) Instrument = 127; else Instrument = Instrument - 1;}
  
          if (Channel==0) Instrument0 = Instrument; else Instrument1 = Instrument;
        }

     if (Bank != 0) Instrument = 0x1E; // Percussion Bank the different notes are the different instruments
     
     byte ProgChange = 0xC0 | Channel;
 
     CWPlayer.sciWrite (VS1053_REG_MODE, 0x0c00);
     delay(100);
     SPI.transfer(ProgChange);
     SPI.transfer(0x00);
     SPI.transfer(Instrument);
     SPI.transfer(0x00);
     delay(100);
     
   }
/**************************************************************************************************************************************/
// write(0xB0 | channel, 0, 0x78);
// write(0xC0 | channel , Intrument);
// Bank Select Number: 0x00: Some MIDI devices have more than 128 Programs (ie, Patches, Instruments, Preset, etc). MIDI Program Change 
// messages only support switching between 128 programs. So, Bank Select Controller (sometimes called Bank Switch) is sometimes used to 
// allow switching between groups of 128 programs. For example, let's say that a device has 512 Programs. It may divide these into 4 
// banks of 128 programs apiece. So, if you want program #129, that would actually be the first program within the second bank. You 
// would send a Bank Select Controller to switch to the second bank (ie, the first bank is #0), and then follow with a Program Change 
// to select the first Program in this bank.
/**************************************************************************************************************************************/
void ChangeBank(byte UpDwn) {
 
  if (UpDwn != 3)
     { delay (100);
       if (Bank == 0x00) { Bank = 0x78;
                           SavedInstrument = Instrument;
                           Instrument = 0x1E;
                         }
       else { Bank = 0x00;
              Instrument = SavedInstrument;
            }
     }
    
  CWPlayer.sciWrite (VS1053_REG_MODE, 0x0c00);
  delay(100);
  SPI.transfer(0xB0);
  SPI.transfer(0x00);
  SPI.transfer(0x00);
  SPI.transfer(0x00);
  SPI.transfer(Bank);
  SPI.transfer(0x00);
  if (UpDwn != 3) ChangeInstr(2);
  delay(300);
}

/************************************/
void LoadUserCode(void) {
  // User application code loading tables for VS10xx
  // See http://www.vlsi.fi/en/support/software/vs10xxpatches.html

  int i = 0;
  while (i< PLUGIN_SIZE) {
    word addr, n, val;
    addr = pgm_read_word (&(plugin[i++]));
    n = pgm_read_word (&(plugin[i++]));
    if (n & 0x8000U) { /* RLE run, replicate n samples */
      n &= 0x7FFF;
      val = pgm_read_word (&(plugin[i++]));
      while (n--) {
        CWPlayer.sciWrite (addr , val);       
      }
    } 
    else {           /* Copy run, copy n samples */
      while (n--) {
        val = pgm_read_word (&(plugin[i++]));
        CWPlayer.sciWrite (addr , val);        
      }
    }
  }
  return;
}

/****************************************/
// Send left and right as bytes
// Volume word v left is MSB right is LSB
// 0 Loud FE Quiet FF  is reset analog
/****************************************/
void ChangeVol(byte UpDwn) 
{
     if (UpDwn==0) { if (Volume<0x2F) Volume = Volume + 1; if (Volume==0x2F) Volume = 0xFE; }      // Softer no wrap-around
     if (UpDwn==1) { if (Volume==0xFE) Volume = 0x2F; else if (Volume>0x00) Volume = Volume - 1; } // Louder
     CWPlayer.setVolume(Volume,Volume); 
     
}
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
